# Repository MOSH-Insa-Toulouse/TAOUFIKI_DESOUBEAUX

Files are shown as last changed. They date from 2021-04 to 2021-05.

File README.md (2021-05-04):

# CAPTEUR DE GRAPHITE TAOUFIKI_DESOUBEAUX
# Sommaire
<!-- TOC depthFrom:2 -->
  - [1. Description](#1-Description)
  - [2. Code Arduino](#2-Code-Arduino)
  - [3. KiCAD](#3-KiCAD)
  - [4. Application Android](#4-Application-Android)
  - [5. Banc de tests](#5-Banc-de-tests)
  - [6. Résultats et discussion](#6-Résultats-et-discussion)
  - [7. Datasheet du capteur](#7-Datasheet-du-capteur)
  - [8. Contact](#8-Contact)
<!-- /TOC -->

# 1. Description 

Ce projet a été réalisé au cours de l'unité de formation "Du Capteur au Banc de Test" de la 4ème année du cursus “Génie Physique” à l’INSA de Toulouse.  L'objectif de ce dernier est la réalisation d'un capteur de déformation à base de graphite, peu onéreux, flexible, léger et écoresponsable.

Ce capteur exploite la dépendance entre la conductivité électrique et la distance entre les nanoparticules de graphite. En  effet, les électrons se déplacent entre les nanoparticules de graphite par effet tunnel. En appliquant de plus une contrainte mécanique, l'échantillon se déforme, ce qui affecte la distance entre les nanoparticules du capteur et modifie ainsi la conductivité électrique, ce qui se traduit par une variation de résistance, qu'on peut alors mesurer.

Pour ce faire, nous allons colorier au crayon la surface du capteur pour laisser une fine couche de graphite sur le papier. Nous avons à notre disposition plusieurs types de crayons et qui se distinguent par la concentration de graphite contenue dans chacun d'entre eux. Nous pourrons ainsi observer différents comportements de résistances en fonction des crayons utilisés.

La chaîne de mesure est basée sur l'acquisition d'un signal associée à la variation de résistance du capteur. Nous avons alors réalisé un shield PCB à l'aide du logiciel KiCad contenant un amplificateur transimpédance, un encodeur rotatoire, un module Bluetooth et un écran OLED. Ce shield est ensuite placé sur une carte Arduino UNO, programmé par un code C++ Arduino à l'aide du logiciel Arduino IDE. Les mesures de résistances sont également trannsmises par Bluetooth et interfacées sur une application Android APK créée sur MIT App Inventor.

# 2. Code Arduino

Pour développer notre code Arduino, nous avons d'abord du installer trois librairies Adafruit : Adafruit_GFX_Library et Adafruit_SSD1306 pour le contrôle de nos modules et Adafruit_BusIO pour la connexion entre SPI et I2C. 

Nous avons ensuite réalisé un code développé sous Arduino IDE, qui nous permet de contrôler un module Bluetooth, un amplificateur transimpédance et un écran OLED et permet la mesure de résistance de notre graphite. Ce code se trouve [ici](/Capteur_de_graphite.ino).

# 3. KiCad

## Empreintes et symboles

- Amplificateur LTC1050

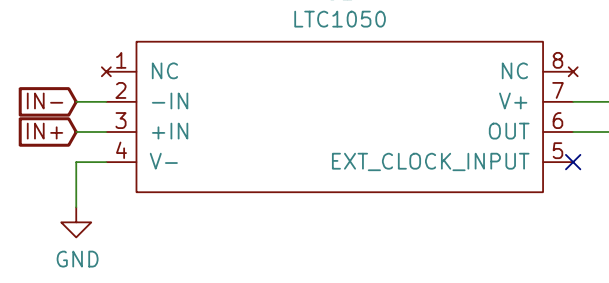
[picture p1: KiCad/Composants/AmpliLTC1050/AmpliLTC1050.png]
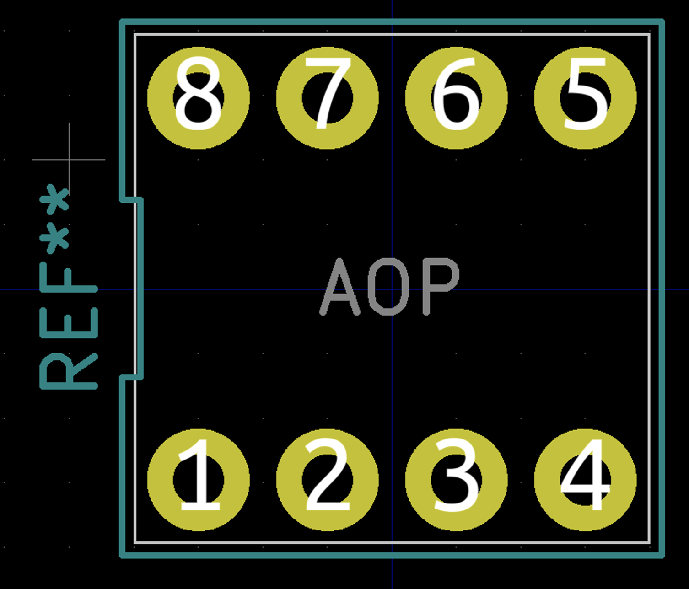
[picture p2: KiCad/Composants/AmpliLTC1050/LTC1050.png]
   

- Module Bluetooth

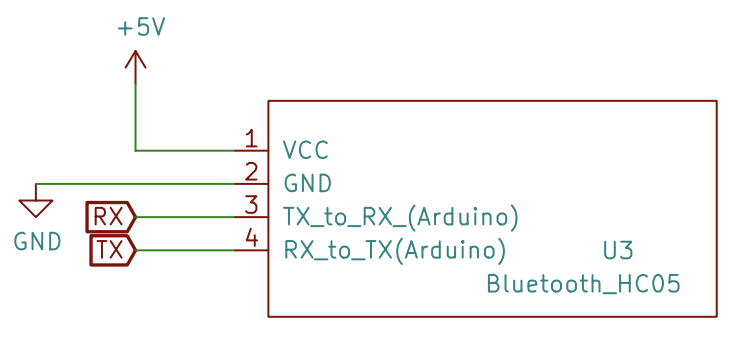
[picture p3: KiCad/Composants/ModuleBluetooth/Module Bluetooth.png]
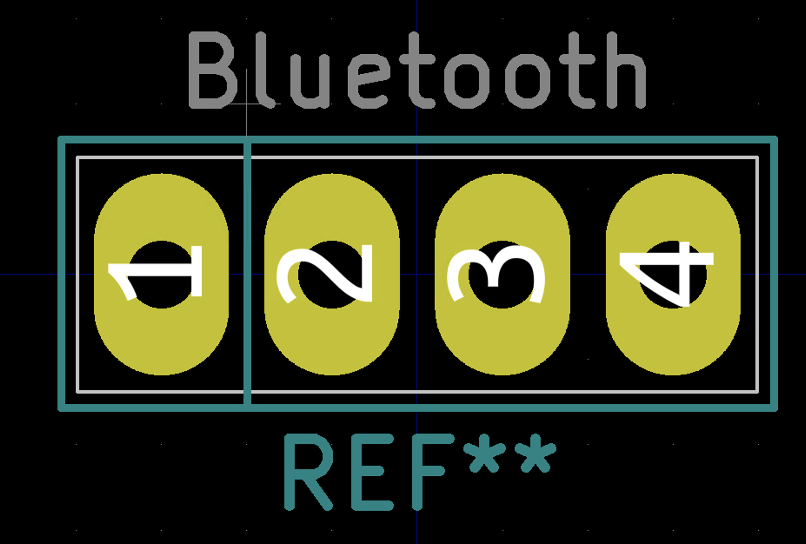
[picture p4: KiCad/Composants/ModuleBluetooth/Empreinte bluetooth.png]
  

- Encodeur rotatoire

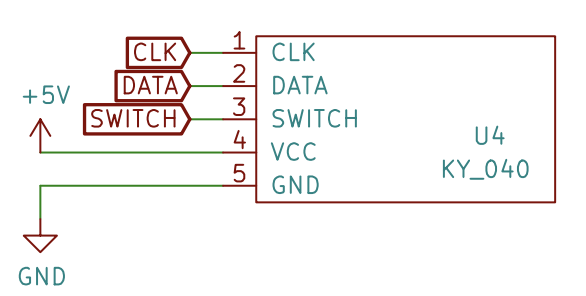
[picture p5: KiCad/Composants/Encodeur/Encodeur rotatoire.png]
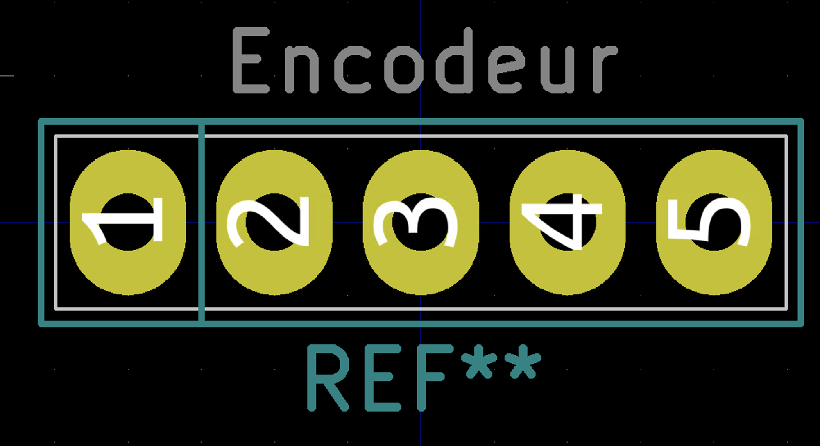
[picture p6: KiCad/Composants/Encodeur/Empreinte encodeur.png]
  

- Ecran OLED

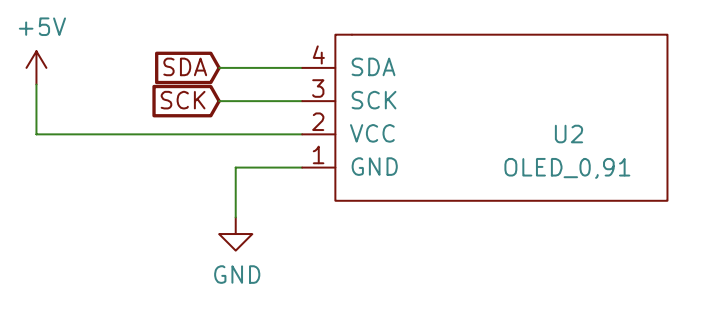
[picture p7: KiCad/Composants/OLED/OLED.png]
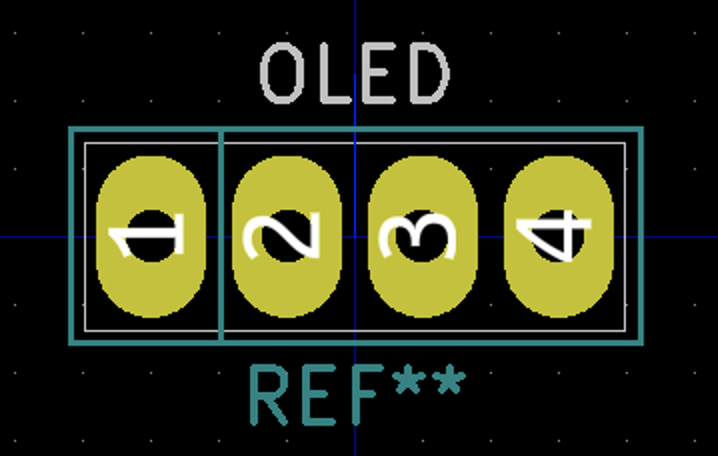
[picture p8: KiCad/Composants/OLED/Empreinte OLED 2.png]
  

## Schématique et circuit

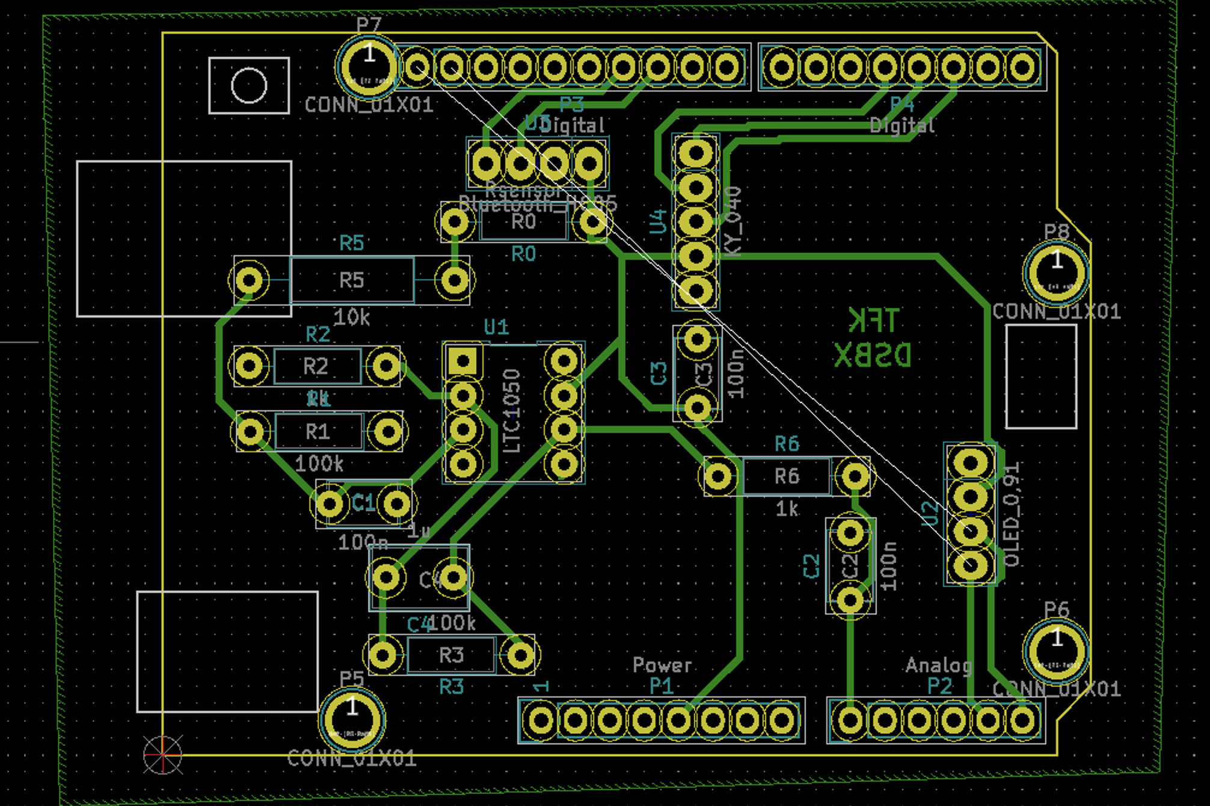
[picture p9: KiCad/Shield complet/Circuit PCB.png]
 
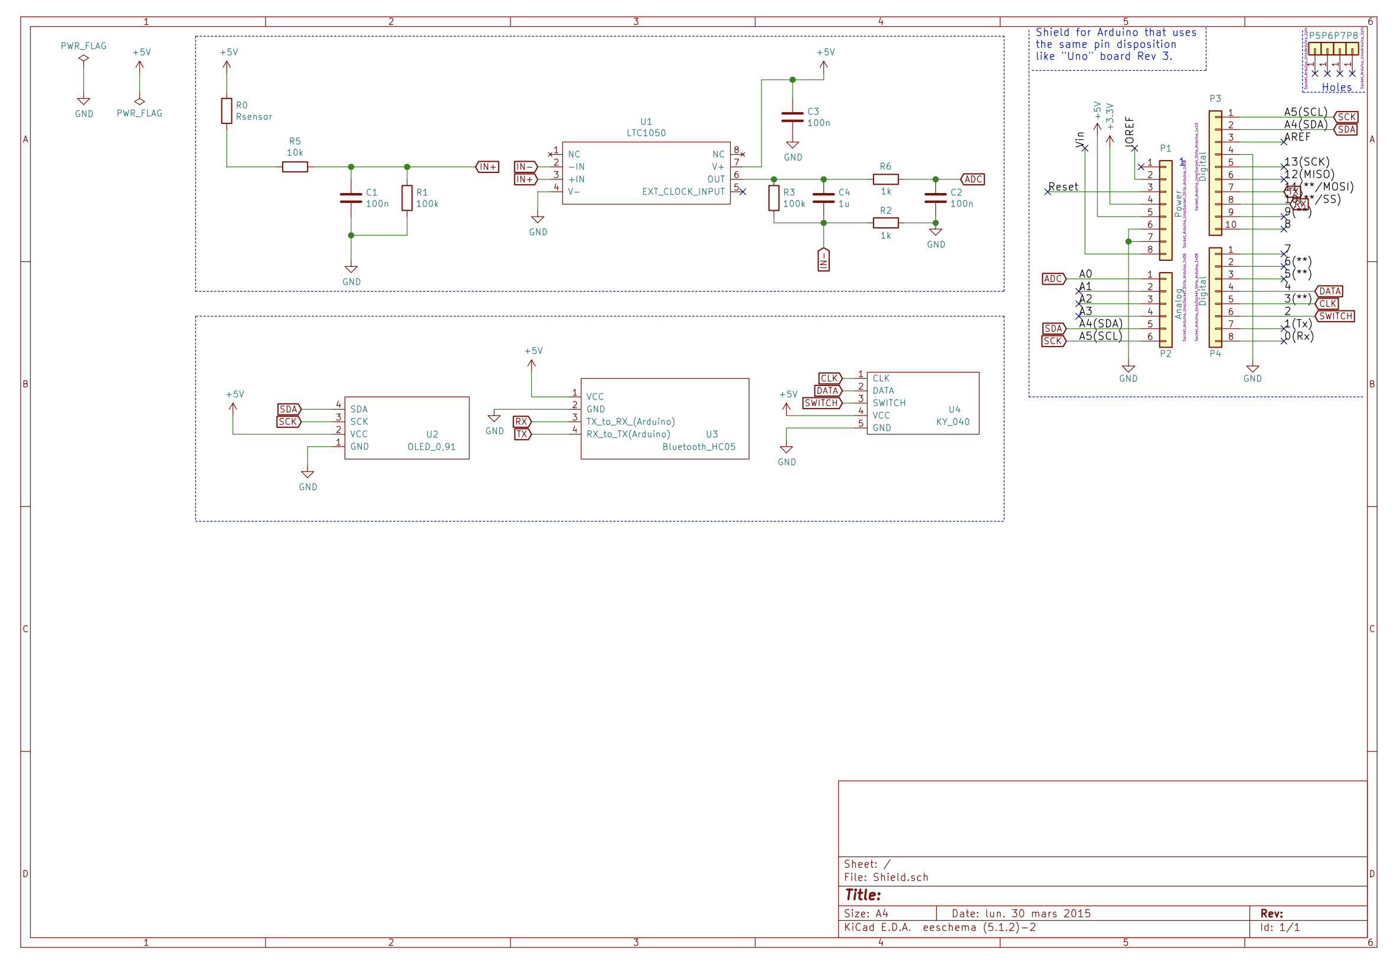
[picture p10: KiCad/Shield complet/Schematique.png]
 

## Visualisation 3D

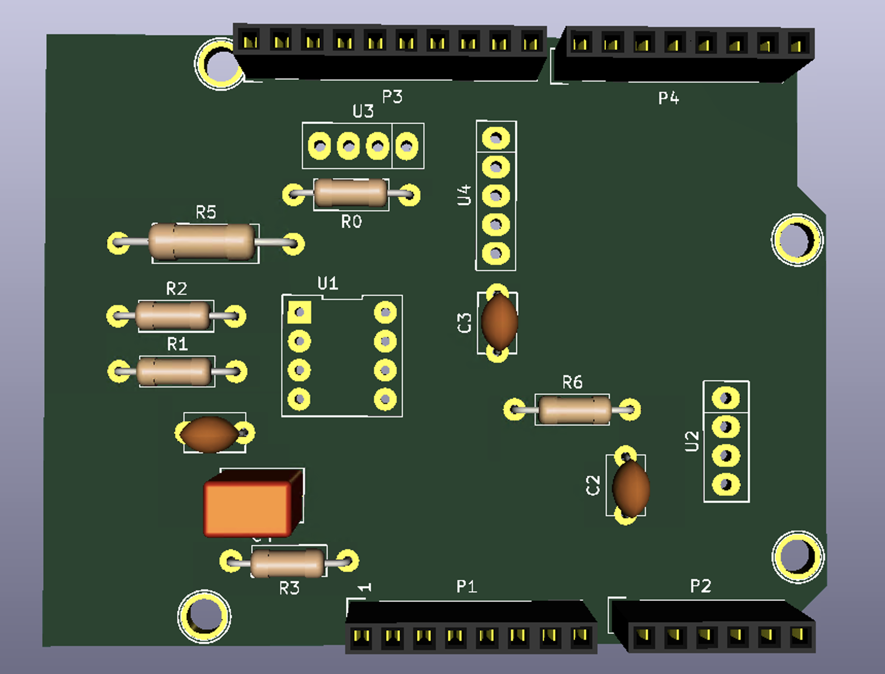
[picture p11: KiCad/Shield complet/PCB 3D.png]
 

# 4. Application Android

Nous avons réalisé une application Android, via le site Internet MIT App Inventor. Celle-ci assure la liaison Bluetooth avec notre Shield et permet d'afficher l'évolution relative de la résistance en temps réel dans un graph.

## Code

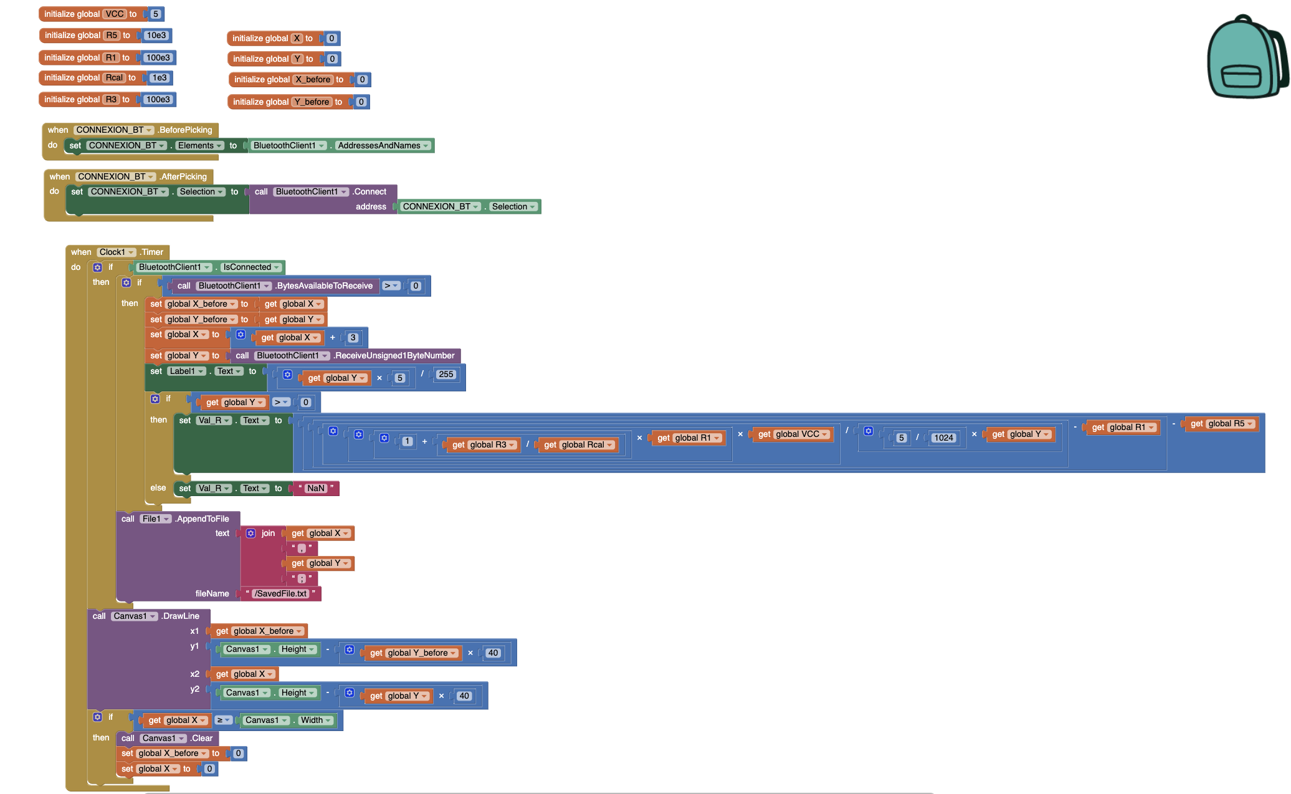
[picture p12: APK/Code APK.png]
 

## Interface

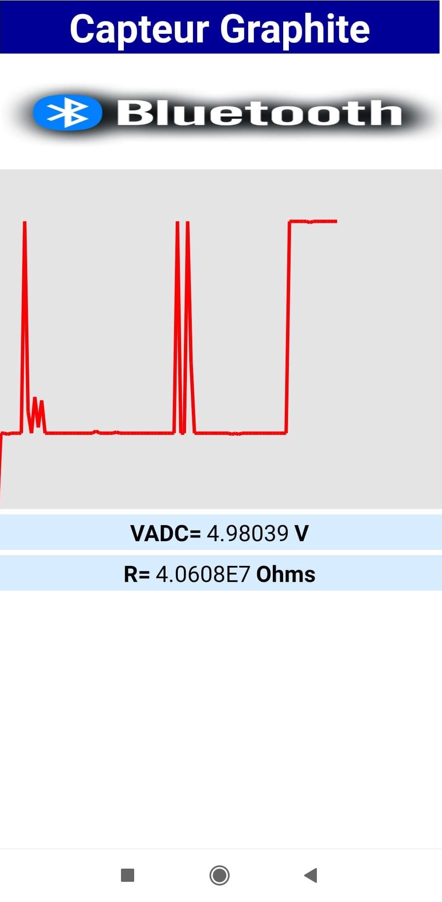
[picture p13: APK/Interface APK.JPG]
 

# 5. Banc de tests

Notre banc de test est composé d'une carte Arduino sur laquelle on a placé notre shield et branchée par un câble USB à l'ordinateur. Les pinces crocodiles permettent d'immobiliser le capteur de graphite et de relever les mesures de résistance.

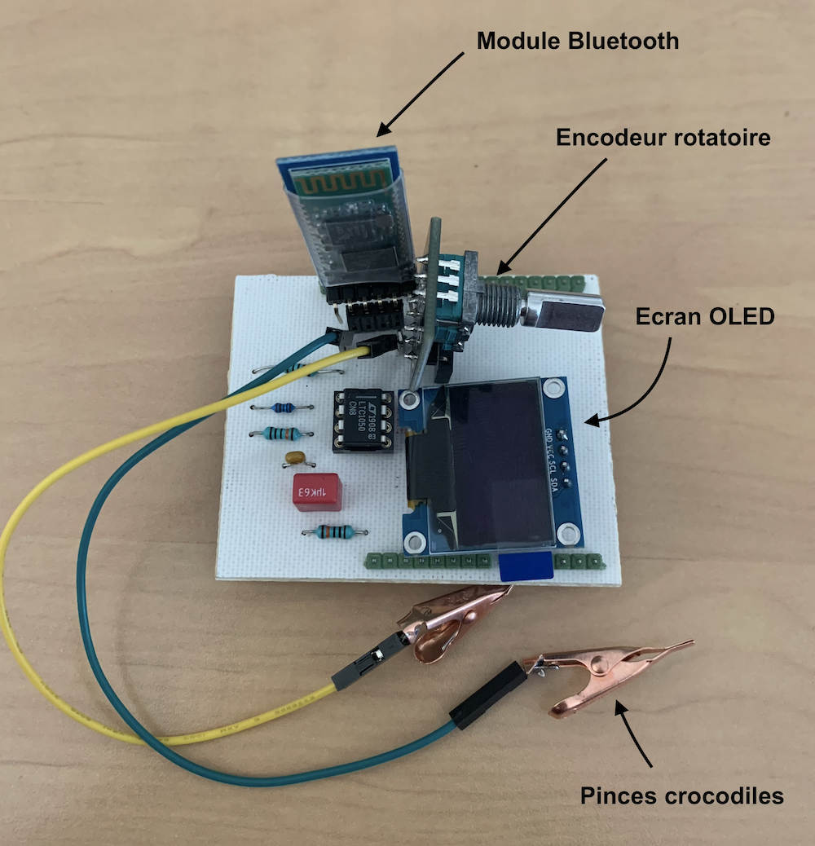
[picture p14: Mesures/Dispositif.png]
 

Afin de mesurer les variations de résistance, nous avons utilisé un dispositif composé de demi-cercles concentriques, dont le rayon varie de 1 à 2,5 cm.

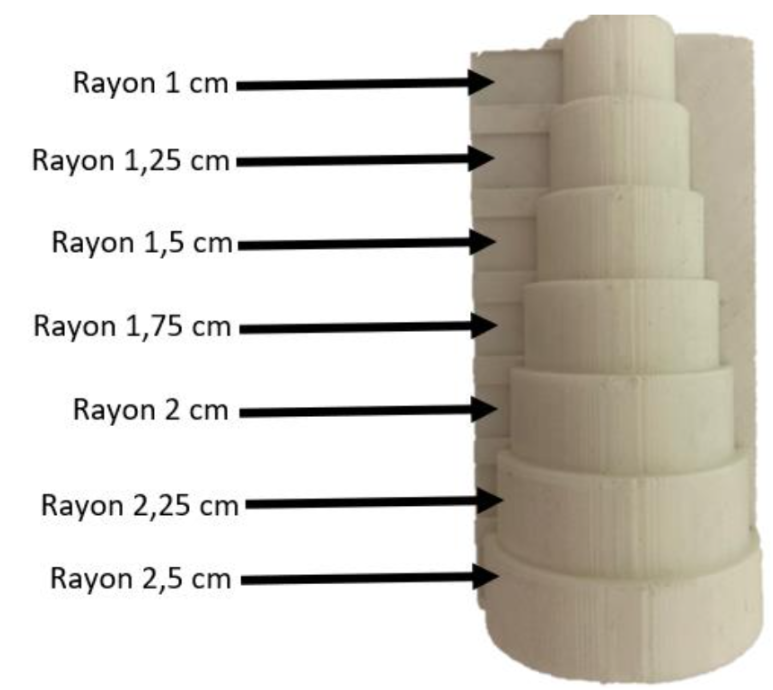
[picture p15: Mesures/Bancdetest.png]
 

On place d'abord les pinces crocodiles sur le capteur, après avoir colorié ce dernier avec le crayon qui nous intéresse pour la mesure. On place ensuite notre capteur sur le demi-cercle au rayon le plus grand, pour éviter de trop abimer le capteur dès le début. On repète cette dernière opération jusqu'à arriver au demi-cercle de plus petit rayon.

# 6. Résultats et discussion

## Résultats
Avec ce banc de tests, nous obtenons les courbes suivantes réalisées sous Python, représentant l'évolution de la variation relative de résistance en fonction de la déformation et leurs courbes de tendance; ainsi qu'un graph comparant les résultats pour les 3 types de crayons testés:

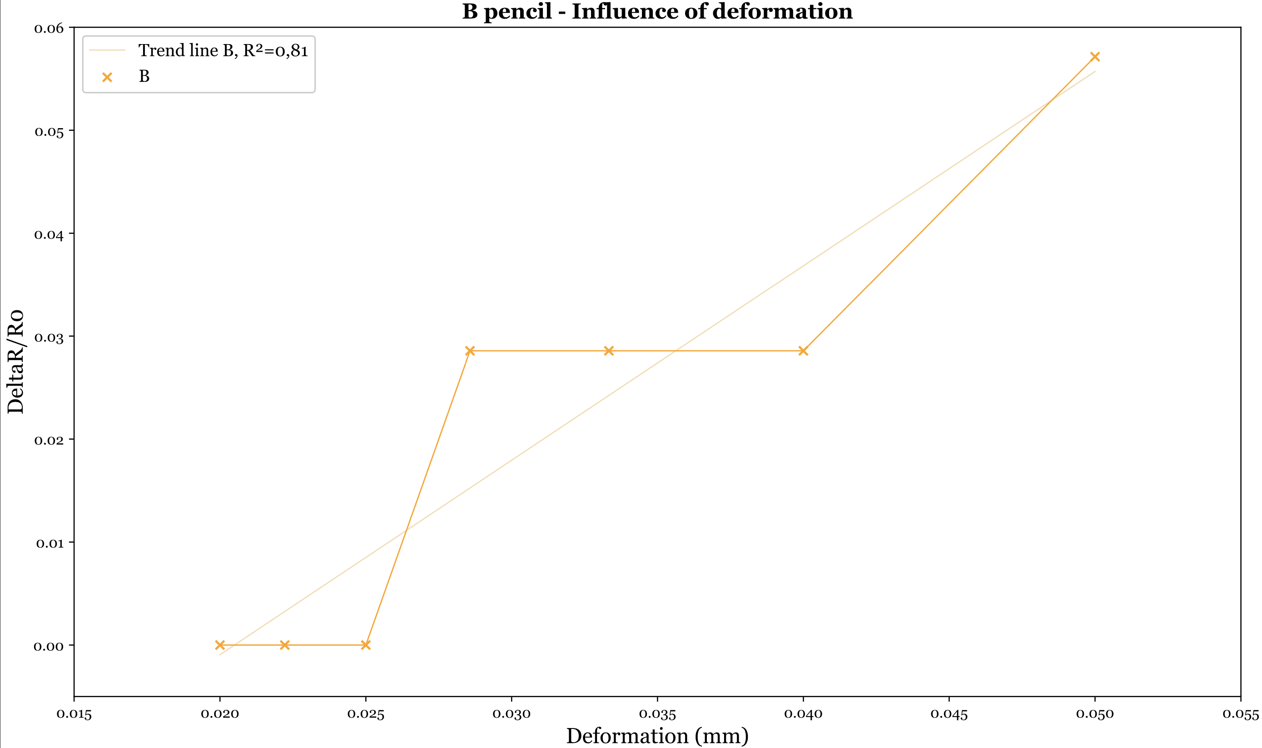
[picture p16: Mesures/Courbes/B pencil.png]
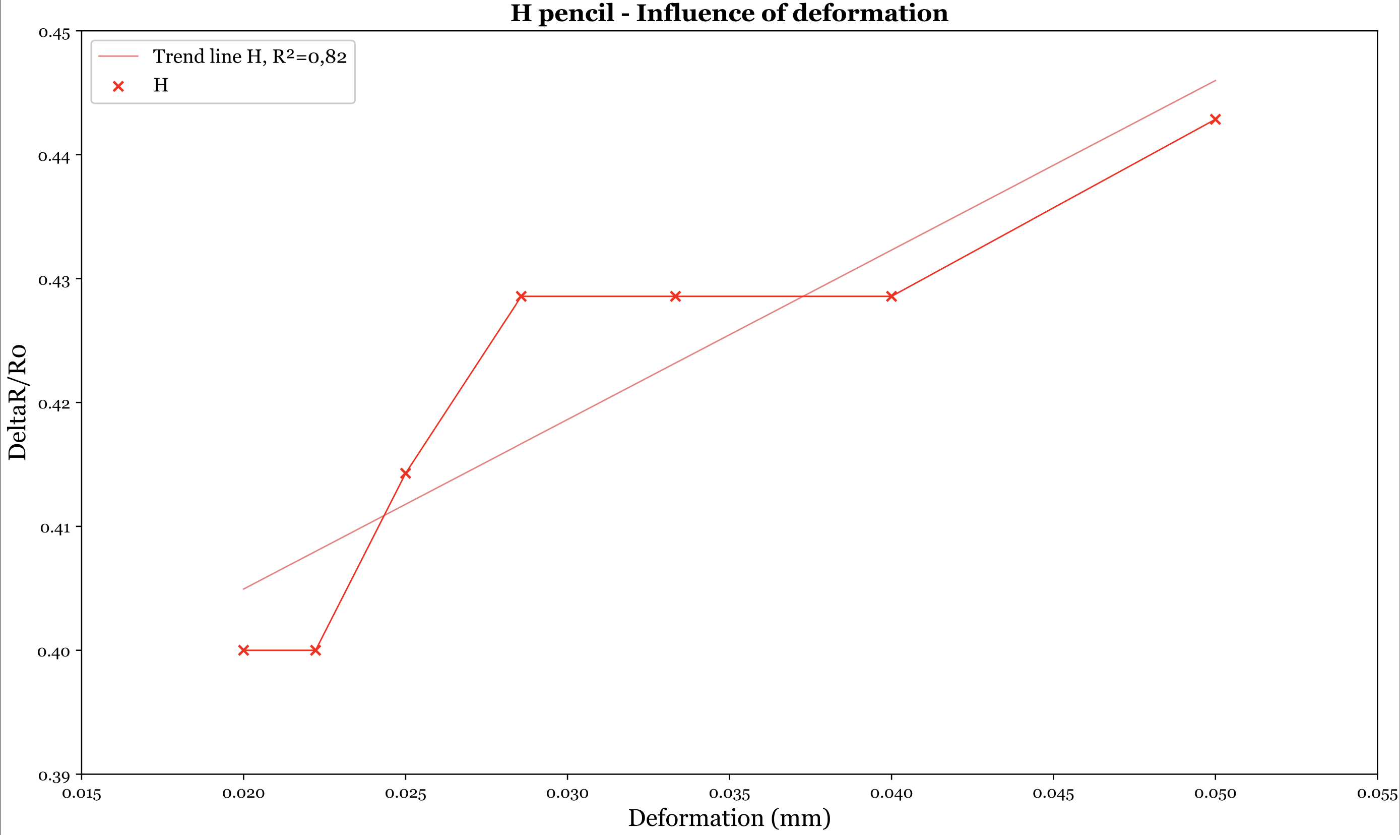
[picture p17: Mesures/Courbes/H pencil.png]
  
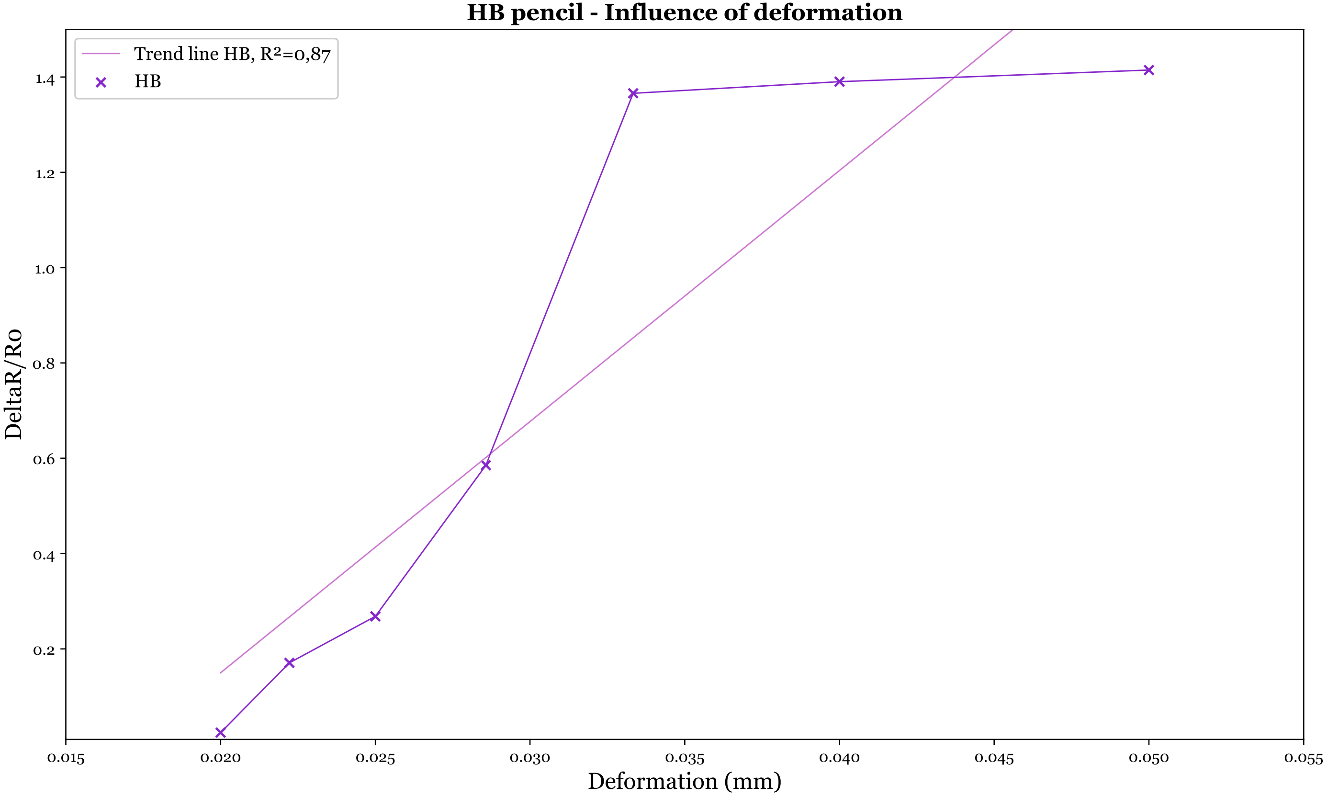
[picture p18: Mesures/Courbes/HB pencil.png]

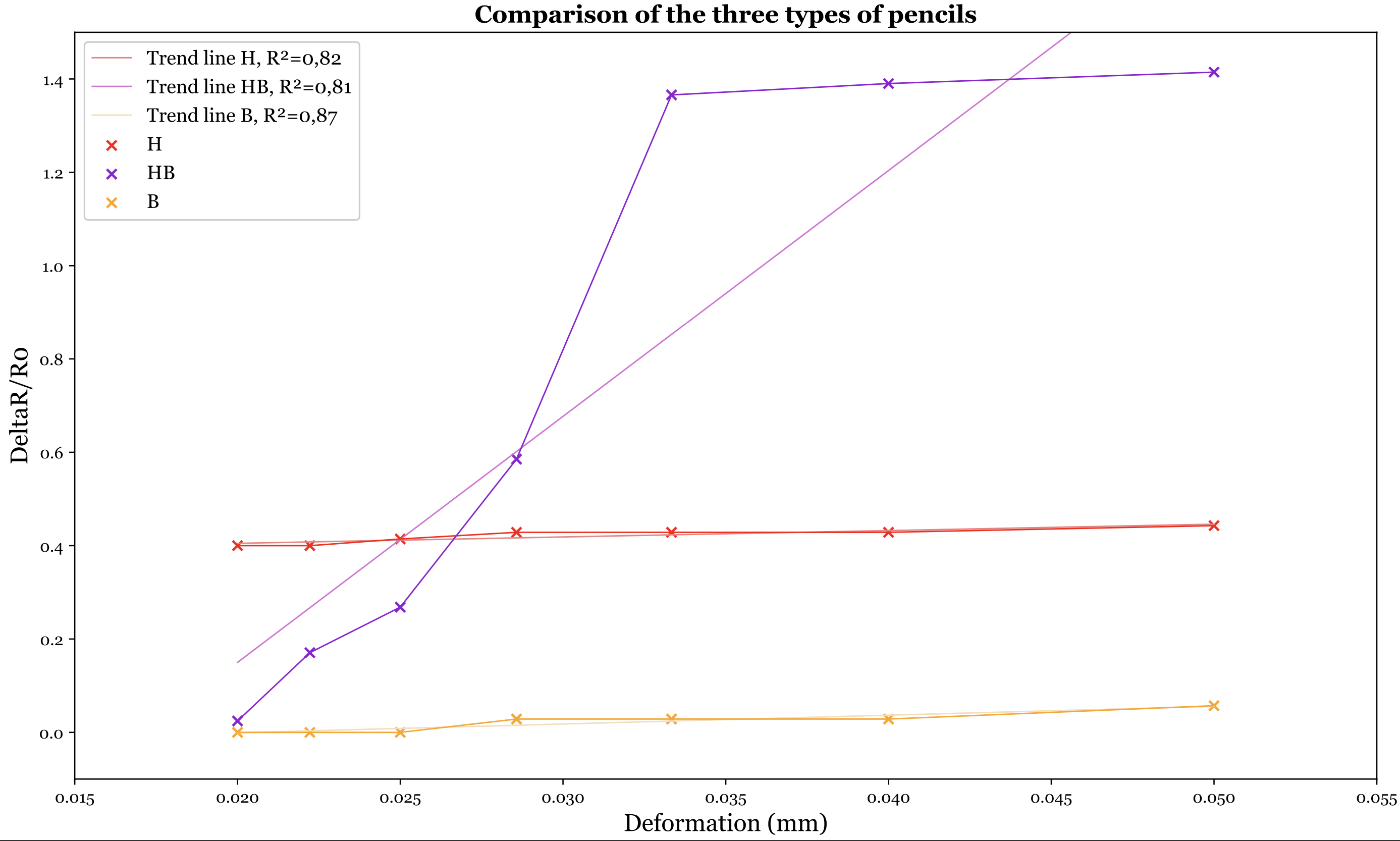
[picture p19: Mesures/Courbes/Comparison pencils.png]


Plusieurs remarques peuvent être faites :
- Les courbes suivent une évolution quasi-linéaire.
- Parmi les trois types de crayons testés, ce sont les variations de résistance des crayons H et B qui semblent les plus constantes en fonction de la déformation. On aurait pu s'attendre à ce que plus le crayon soit dur, plus la variation de résistance soit élevée. Ce n'est pas notre cas ici. Il aurait fallu tester avec plus de crayons différents pour voir une tendance plus marquée ou faire plus d'essais. Vous pouvez retrouver le détail des mesures rassemblées dans un fichier Excel [ici](/Mesures).
- Nous obtenons comme facteurs de jauge : 1,37 pour le crayon H, 1,89 pour le crayon B et 52,7 pour le crayon HB.

## Discussion

Deux limites principales sont ici à mentionner quant à l'utilisation de ce banc de tests :
- La non-répétabilité des mesures : en effet, lors du relevé des mesures, le plus infime des mouvements pouvait faire varier la résistance du tout au tout, il était donc difficile d'obtenir des valeurs de résistance proches l'une de l'autre d'un essai à l'autre.
- Le dépôt de graphite : déposer trop peu de graphite pouvait entraîner des problèmes de continuité électrique; il faut aussi prendre en compte la précision du tracé ou encore la pression du crayon sur le papier qui peut varier d'un essai à l'autre et entraîner des variations du facteur de jauge.

# 7. Datasheet du capteur

Vous pouvez retrouver notre datasheet [ici](/Datasheet).

# 8. Contact

Nous tenons à remercier tous nos professeurs pour leur aide lors de l'élaboration de ce projet, notamment M. Grisolia, Mme. Crouzet et M. Biganzoli.

Pour toute question, merci de nous contacter : 
- Ines TAOUFIKI : taoufiki@etud.insa-toulouse.fr
- Juliette DESOUBEAUX : desoubea@etud.insa-toulouse.fr

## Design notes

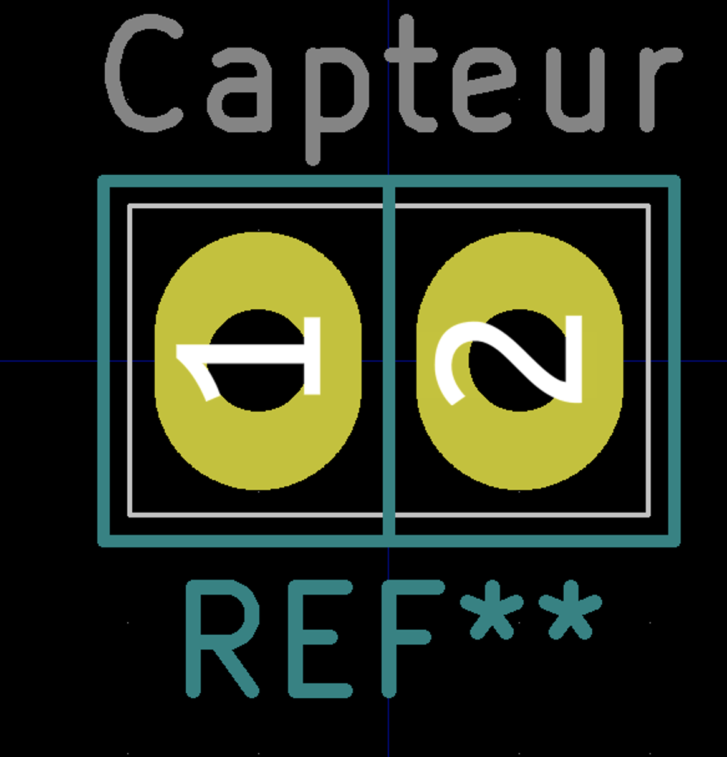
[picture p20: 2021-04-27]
KiCad/Composants/Capteur/Empreinte capteur.png

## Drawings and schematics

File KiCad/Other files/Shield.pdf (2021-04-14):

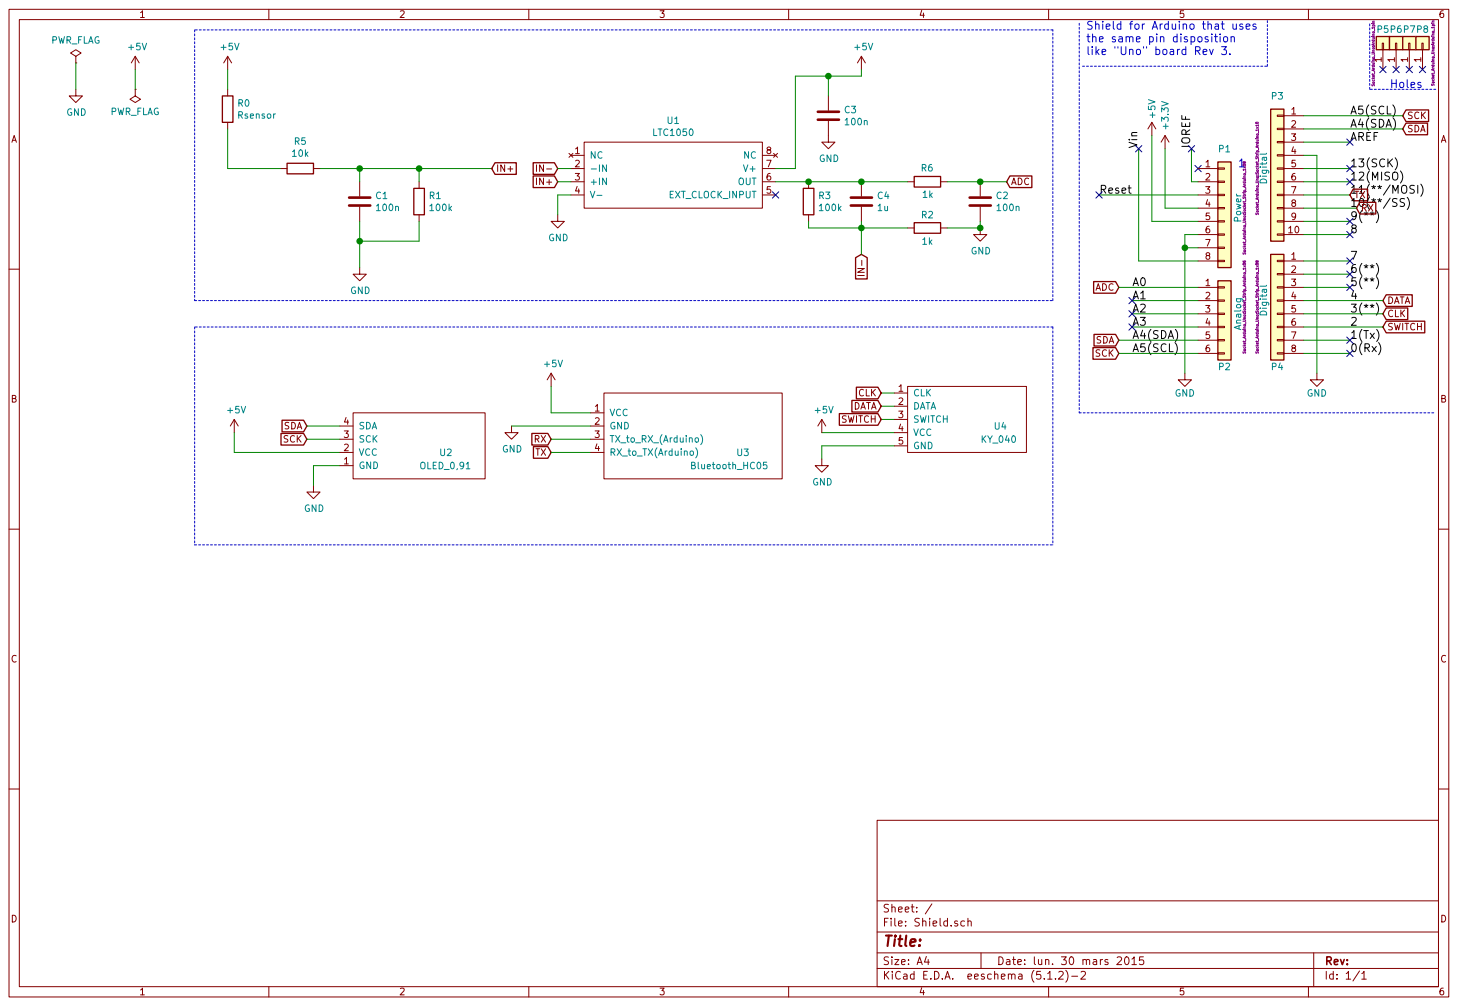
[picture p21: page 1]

A5(SCL)Holes Shield for Arduino that uses
the same pin disposition
like "Uno" board Rev 3. 1

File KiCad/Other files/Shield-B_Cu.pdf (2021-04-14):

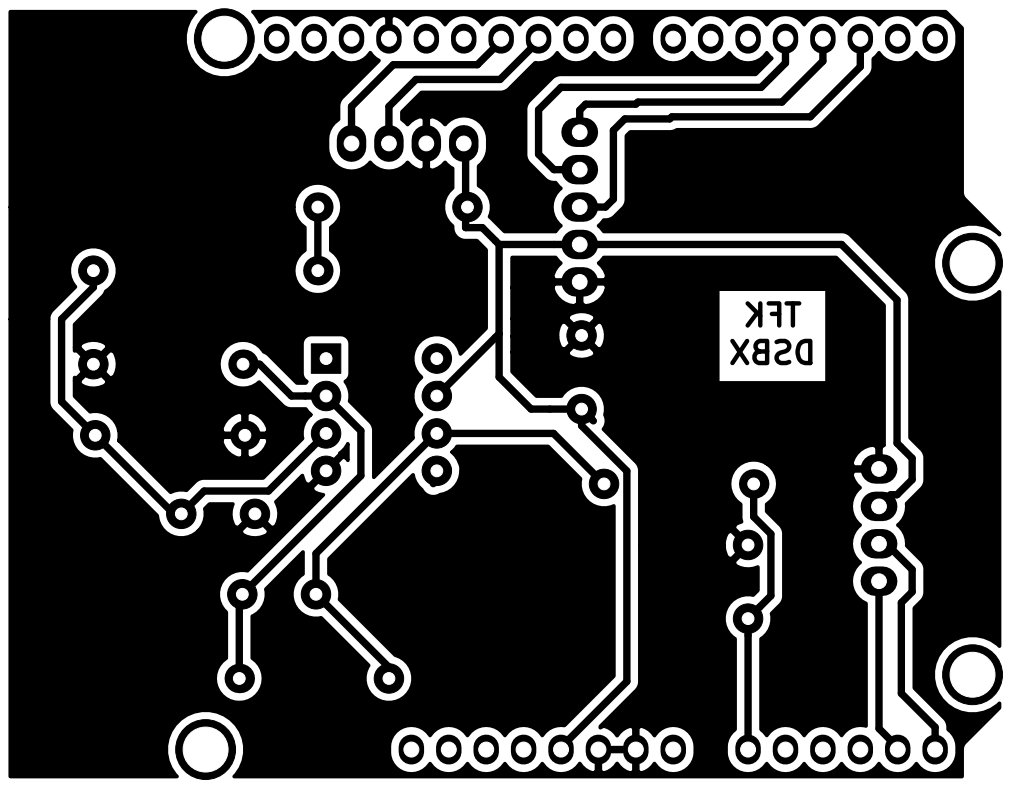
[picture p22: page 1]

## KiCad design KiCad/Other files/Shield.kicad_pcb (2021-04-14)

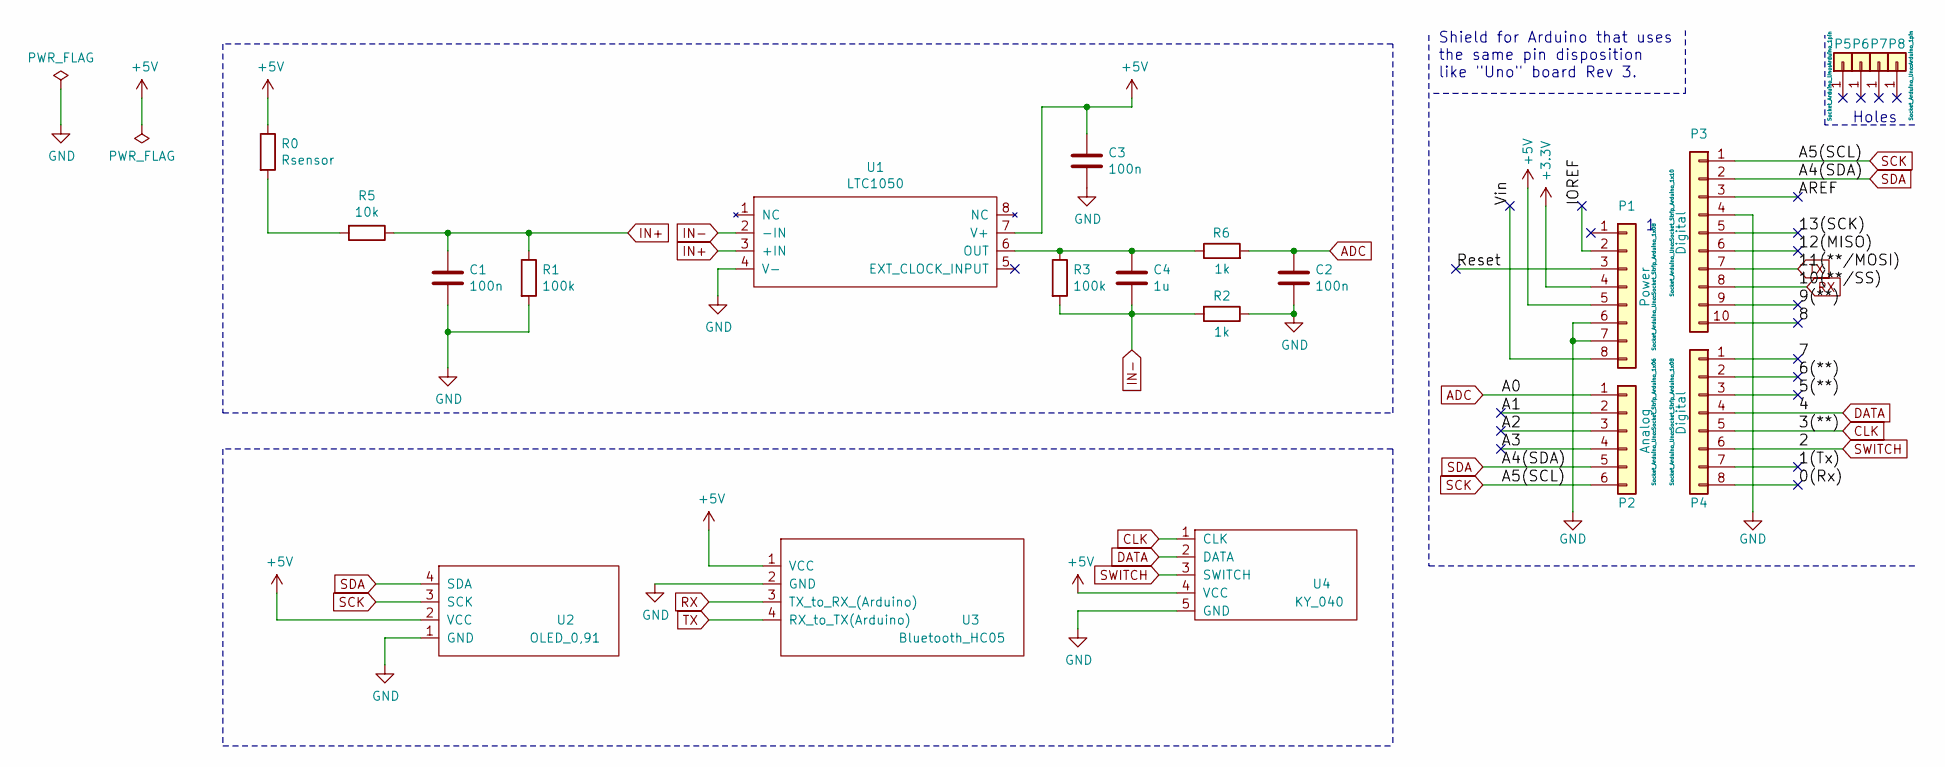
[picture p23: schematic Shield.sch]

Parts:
C1, C2, C3: 100n; C_Disc_D5.1mm_W3.2mm_P5.00mm
C4: 1u; C_Rect_L7.0mm_W4.5mm_P5.00mm
P1: Power; Socket_Strip_Arduino_1x08
P2: Analog; Socket_Strip_Arduino_1x06
P3: Digital; Socket_Strip_Arduino_1x10
P4: Digital; Socket_Strip_Arduino_1x08
P5, P6, P7, P8: CONN_01X01; Arduino_1pin
R0: Rsensor; R_Axial_DIN0207_L6.3mm_D2.5mm_P10.16mm_Horizontal
R1, R3: 100k; R_Axial_DIN0207_L6.3mm_D2.5mm_P10.16mm_Horizontal
R2, R6: 1k; R_Axial_DIN0207_L6.3mm_D2.5mm_P10.16mm_Horizontal
R5: 10k; R_Axial_DIN0309_L9.0mm_D3.2mm_P15.24mm_Horizontal
U1: LTC1050; AOP
U2: OLED_0,91; Mon_Bluetooth
U3: Bluetooth_HC05; Mon_Bluetooth
U4: KY_040; Encodeur

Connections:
+3V3: P1.4
+5V: C3.1, P1.5, R0.1, U1.7 (V+), U2.2 (VCC), U3.1 (VCC), U4.4 (VCC)
/0(Rx): P4.8
/1(Tx): P4.7
/5(**): P4.3
/6(**): P4.2
/7: P4.1
/8: P3.10
/9(**): P3.9
/12(MISO): P3.6
/13(SCK): P3.5
/A1: P2.2
/A2: P2.3
/A3: P2.4
/AREF: P3.3
/IOREF: P1.2
/Reset: P1.3
/Vin: P1.8
ADC: C2.1, P2.1, R6.2
CLK: P4.5, U4.1 (CLK)
DATA: P4.4, U4.2 (DATA)
GND: C1.2, C2.2, C3.2, P1.6, P1.7, P3.4, R1.2, R2.1, U1.4 (V-), U2.1 (GND), U3.2 (GND), U4.5 (GND)
IN+: C1.1, R1.1, R5.1, U1.3 (+IN)
IN-: C4.2, R2.2, R3.2, U1.2 (-IN)
unnamed: C4.1, R3.1, R6.1, U1.6 (OUT)
unnamed: R0.2, R5.2
RX: P3.8, U3.3 (TX_to_RX_(Arduino))
SCK: P2.6, P3.1, U2.3 (SCK)
SDA: P2.5, P3.2, U2.4 (SDA)
SWITCH: P4.6, U4.3 (SWITCH)
TX: P3.7, U3.4 (RX_to_TX(Arduino))

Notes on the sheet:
Holes
Shield for Arduino that uses the same pin disposition like "Uno" board Rev 3.

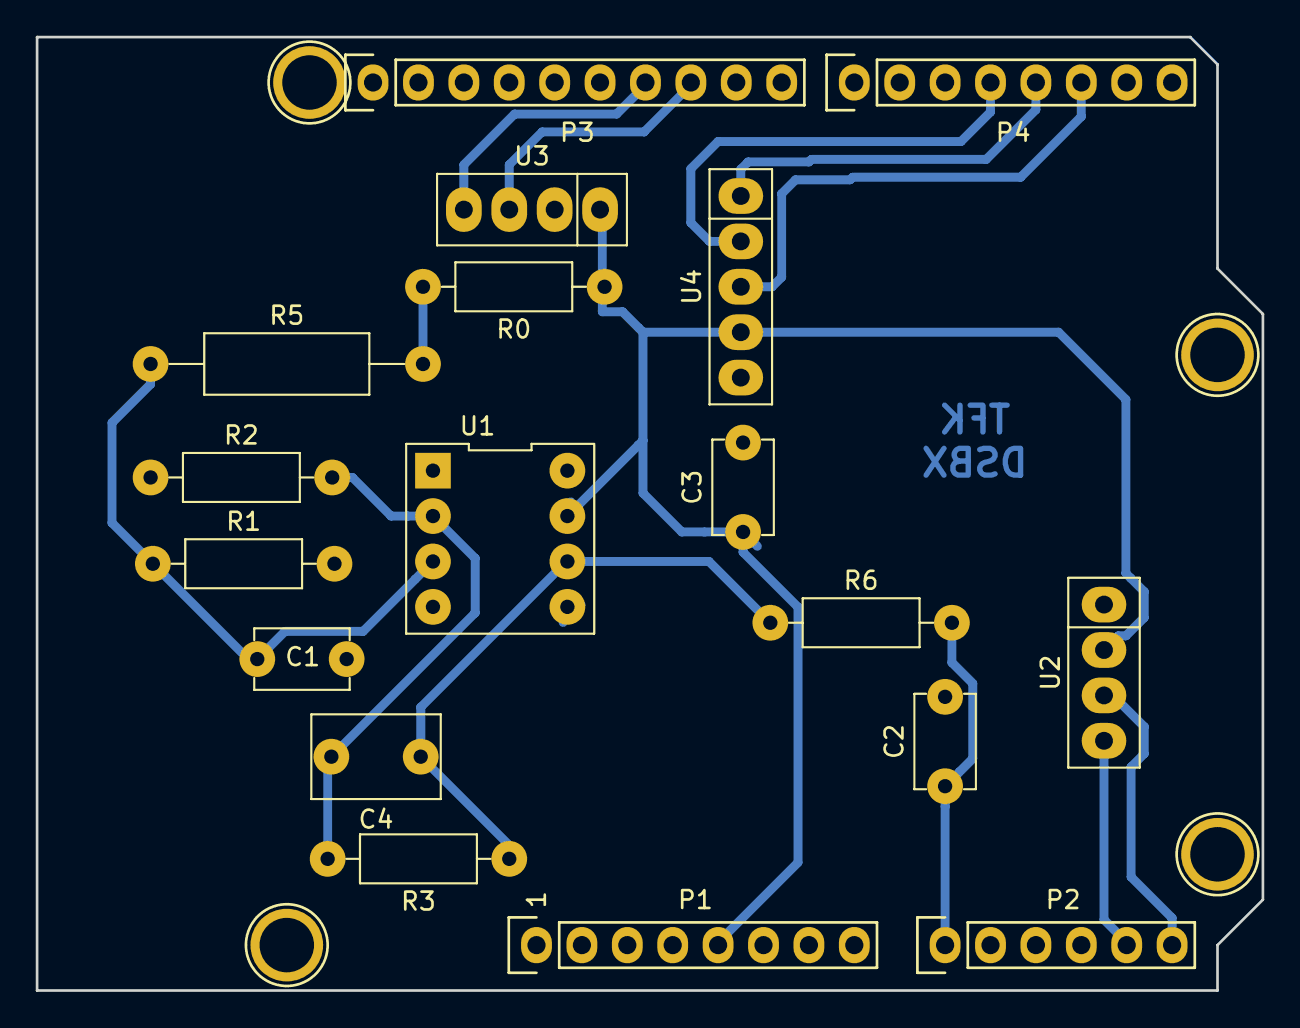
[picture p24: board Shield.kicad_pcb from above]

Board: 2 copper layers, 68.6 x 53.3 mm, 22 parts (0 on the bottom side), 14 nets.

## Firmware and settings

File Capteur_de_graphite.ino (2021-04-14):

//____________________Library____________________//
#include <stdio.h>
#include <SoftwareSerial.h>
#include <SPI.h>
#include <Wire.h>
#include <Adafruit_GFX.h>
#include <Adafruit_SSD1306.h>      

//__________PORTS AND VARIABLES' DEFINITION_______//

/*OLED*/
#define SCREEN_WIDTH 128 // OLED display width, in pixels
#define SCREEN_HEIGHT 64 // OLED display height, in pixels
#define OLED_RESET -1 //Reset pin shared with the arduino reset button
Adafruit_SSD1306 display(SCREEN_WIDTH, SCREEN_HEIGHT, &Wire, OLED_RESET);

/*Bluetooth*/
#define rxPin 10 
#define txPin 11
SoftwareSerial HC05(rxPin ,txPin); //Software serial definition
#define baudrate 9600

/*Roto Encoder*/
#define encoder0PinCLK  3 //Clock Output of the Roto Encoder
#define encoder0PinDT  4  //Data Output of the Roto Encoder
#define Switch 2 //Switch connection of the Roto Encoder

int encoderPos=0; //Position of the Roto Encodeur
long unsigned tempsA ; //Clock setup
int rotoTimer = millis(); //Clock loop


/*Measure*/
#define TensionEntree A0 //Pin used to measure the Sensor
float VADC = 0.0; //Tension (0 = 0V; 1024 = 5V)
byte tensionHC05; //Tension send to the APK
double R0 = 0.0; //Resistor R0
float offset=1.10;
float mesure = 0.0; //Tension calibrated

//____________________SETUP____________________//
void setup() {
  
  /*Bluetooth Configuration*/
  pinMode(rxPin,INPUT);
  pinMode(txPin,OUTPUT);
  HC05.begin(baudrate);   

  /*Roto Encoder Confuguration */
  pinMode(encoder0PinCLK, INPUT); 
  digitalWrite(encoder0PinCLK, HIGH);
  pinMode(encoder0PinDT, INPUT); 
  digitalWrite(encoder0PinDT, HIGH); 
  tempsA = millis();
    
  /*OLED Confuguration*/
  /*if(!display.begin(SSD1306_SWITCHCAPVCC, 0x3C)) { // Address 0x3C for 128x32 sreen
    Serial.println(F("SSD1306 allocation failed"));
    for(;;);
  }*/
    
  display.begin(SSD1306_SWITCHCAPVCC, 0x3C); // Address 0x3C for 128x32 sreen
  display.display();
  delay(2000);
  display.clearDisplay();

  /*Introduction to our sensor on the OLED screen*/
  display.setTextSize(1);
  display.setTextColor(WHITE);
  display.setCursor(40,7);
  display.println(F("Capteur"));
  display.setCursor(29,17);
  display.println(F("de graphite"));
  display.drawRoundRect(2, 2, 124,30, 4, WHITE);
  display.display();
  delay(2000);
  display.clearDisplay();

  /*Introduction to our sensor operation on the OLED screen*/
  display.setTextSize(2);
  display.setTextColor(WHITE);
  display.setCursor(30,7);
  display.println(F("Choix"));
  display.setTextSize(1);
  display.setCursor(37,35);
  display.println(F("Tension"));
  display.setCursor(15,48);
  display.println(F("<- Resistance ->"));
  display.display();
  delay(2000);
  display.clearDisplay();
}

//____________________MAIN LOOP____________________//
void loop(){

  rotoTimer = millis();
  
  /*Measure of the tension on the pin A0 and calculation of the average value of the last five values*/
  VADC = analogRead(TensionEntree)*5.0/1024.0;

  /*Calculation of the Tension calibrated*/   
  mesure = VADC - offset;

  /*Calculation of the value of the resistance*/
  if(mesure > 0){
    R0 = (float)((1.0+100000.0/1000.0)*100000.0*(5.0/mesure)-100000.0-10000.0)/1000000.0 ;
  }else{
    R0 = -1;
  }  

  /*Calculation of the value of the pin A0 for the Bluetooth*/
  tensionHC05= map (analogRead(TensionEntree),0,1024,0,255)-offset;
  /*Sending and Reading of the value of the pin A0 on the APK*/
  HC05.write(tensionHC05);
  while (HC05.available()){
    HC05.read();  
  }
  display.clearDisplay();
  /*Reading of the R0 value when we turn the Roto Encoder*/
  if (digitalRead(encoder0PinDT) == LOW || encoderPos==1){
    ConfigText("R =",0,4,5,1);
    ConfigText("NaN",R0,4,20,2);
    ConfigText("MO",0,90,20,2);
    display.display();
    delay(4000);
    display.clearDisplay();
    encoderPos=1;
  }

  /*Reading of the Tension (pin A0) value when the Roto Encodeur is motionless*/  
  if (digitalRead(encoder0PinDT) == HIGH || encoderPos==2) {
    ConfigText("Tension =",0,4,5,1);
    ConfigText("NaN",mesure,4,20,2);
    ConfigText("V",0,80,20,2);
    display.display();
    delay(400);
    display.clearDisplay();
    encoderPos=2;
  }
}

/*Fonction that configure a text on the OLED screen*/ 
void ConfigText(String text, double val, int x, int y,int size){
  display.setTextSize(size);
  display.setTextColor(WHITE);
  display.setCursor(x,y);
  if (text=="NaN"){
    display.println(val);}
  else{
    display.println(text);
  }
   delay(100);
}
